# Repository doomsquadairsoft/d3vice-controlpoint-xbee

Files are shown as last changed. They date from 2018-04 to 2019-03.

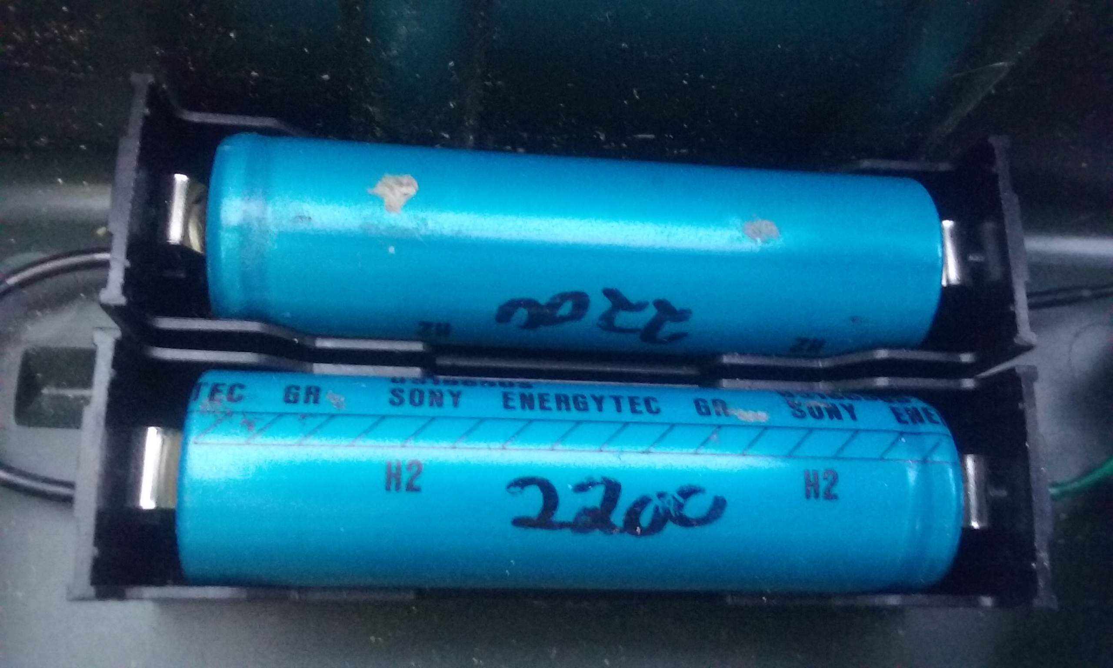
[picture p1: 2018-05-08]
other/pics/batteries.jpg

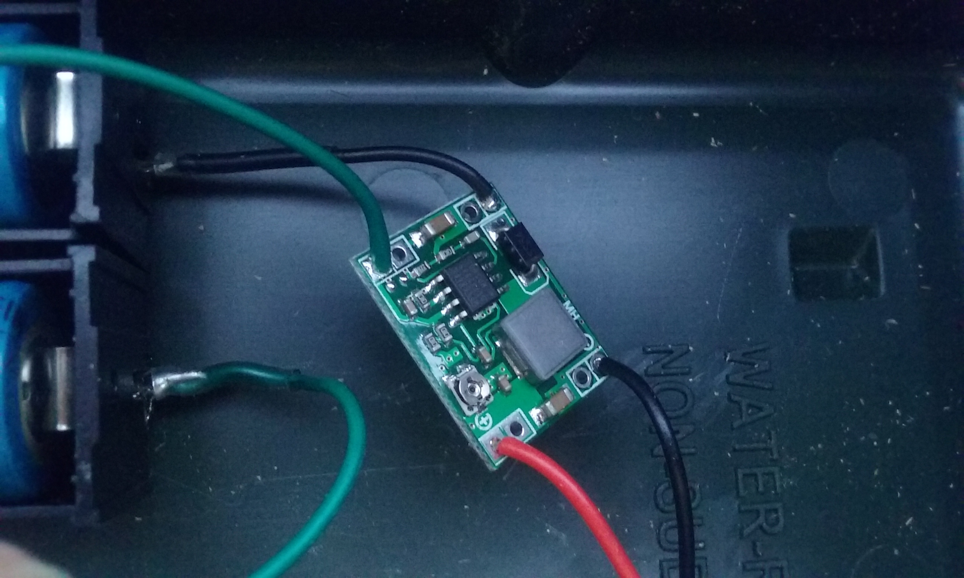
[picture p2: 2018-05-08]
other/pics/regulator.jpg

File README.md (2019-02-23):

# d3vice-controlpoint-xbee
Arduino Fio / XBee based D3VICE control point for Airsoft games

## Feedback

If you have used and enjoy this code base, I'd love to hear from you!



## Development setup process

  * Download, Install [Atom editor](https://atom.io)
  * Download, Install [Platformio](https://platformio.org/install/ide?install=atom) Atom package
  * Restart atom. Open Atom & PlatformIO then import this repo.

??? @TODO once I figure out the process after this
  * Install contributed libraries `Sketch > Include Libraries > Manage Libraries`
    * Adafruit NeoPixel library
    * XBee-Arduino library
  * Add your user account to tty and dialout groups (May or may not be required for your OS)
    * `sudo usermod -aG tty,dialout <YOUR_USERNAME_HERE>`

## Enclosure Ideas

  * [MTM Survivor Dry Box with O-Ring Seal, Large](https://www.amazon.com/MTM-Survivor-Ring-Orange-Large/dp/B002KENWZY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)
  * [Seahorse SE-300 Protective Case Without Foam](https://www.amazon.com/Seahorse-Protective-Case-without-Orange/dp/B001A1TR1Q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)

## XBee

### Setup

To connect to the XBee, a [SparkFun FTDI Basic Breakout 3.3v](https://www.sparkfun.com/products/9873) is used along with an [Adafruit XBee Adapter kit v1.1](https://www.adafruit.com/product/126). As my Adafruit XBee adapter kit v1.1 is discontinued, the replacment seems to be Adafruit's [USB XBee Adapter](https://www.adafruit.com/product/247) which I haven't tested but should do the trick. A separate FTDI chip isn't necessary with that new model.

XCTU is the program for configuring XBee modules. It is cross-platform.

57600 baudrate

Set the controlpoint as an ZB Router API NOT a ZB Endpoint API! Endpoint will work, but has complications with sleep mode.

#### XCTU Troubleshootinghttps://www.youtube.com/watch?v=ChCHfJoo9CQ

Make sure if using it on linux, you add yourself to the `dialout` group. Example: `sudo usermod -a -G dialout chris`

Make sure Arduino IDE is closed when working with XCTU. Radio discovery can be finnicky, but it works when it works.

XCTU's download links on Digi's website are usually broken. Find the filename from the [download page](https://www.digi.com/products/xbee-rf-solutions/xctu-software/xctu#productsupport-drivers), then manually browse their [ftp server](ftp://ftp1.digi.com/support/utilities/) for the correct version of XCTU.

If you can't get XCTU to communicate with your XBee, the rule of thumb is keep trying. It doesn't always work the first or second time. Try the different connection methods as well, from discovery to manually entering XBee serial/USB configuration.

### Power

The XBee is very sensitive when it comes to power. It needs as close to 3.3V as possible. When using USB, the Fio gives it a clean 3.285V. 3.296 was acheived using the buck converter regulator and that seemed to do the trick. If you are attempting to remotely program the XBee using X-CTU, and the read process seems slow, it may be that the XBee is crashing when it tries to pull power. Check voltages and try again.

### IDs

#### PAN ID

0x73706F6B616E6561 (ASCII spokanea)

#### switzerland-robust

SH 0013A200
SL 40B51A26

#### borders-portals

SH 0013A200
SL 40B774EC

## Special Thanks

The following people have helped this project in some way, and deserve a mention. Thank you all for helping this project become a reality!

  * [BulldogLowell](https://forum.arduino.cc/index.php?action=profile;u=258955) for helping me with code when I got stuck
  * [gfvalvo](https://forum.arduino.cc/index.php?action=profile;u=557197) for helping me with code when I got stuck
  * [Jiggy-Ninja](https://forum.arduino.cc/index.php?action=profile;u=53253) a.k.a. [MarkRD](https://hackaday.io/MarkRD) for helping me with code when I got stuck

## Todo list

  * [x] Fix phase 3 issue where ttw is ???
  * [ ] Implement XBee
  * [ ] Implement debugging via XBee wireless link
  * [x] Fix button debounce issue
  * [x] Fix endless beep on phase >=1
  * [x] Add button hold logic
  * [x] Implement ButtonManager
  * [ ] Try LoRa radio [Moteino](https://lowpowerlab.com/shop/product/119) looks nice.

## Parts list

  * (2) 220 Ohm resistor (JP3 button LEDs) DEPRECATED -- The buttons have their own capacitor
  * (3) 10K Ohm resistor (x2 JP4 button switches, x1 Battery Voltage Divider)
  * (1) 100K Ohm resistor (Battery voltage divider)
  * (1) 470 Ohm resistor (R1 Level shifter)
  * (1) 100 Ohm resistor (R2 buzzer)
  * (1) [Arduino Fio](https://amzn.to/2vkoAoj)
  * (1) 900MHz series XBee S2B
  * (1) [Digi JF1R6-CR3-4I U.FL fem to RPSMA fem cable](https://www.mouser.com/productdetail/digi-international/jf1r6-cr3-4i?qs=YPg7lQ8MWSd%252bJ21AYb5tjA%3D%3D)
  * (1) [2.4GHz dipole antenna](https://www.mouser.com/ProductDetail/Laird-LS-Research/001-0001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) (@TODO this doesn't seem right)
  * (1) 5V Buzzer
  * (1) 1000 uF electrolytic capacitor
  * (1) [TI 74AHCT125](http://adafru.it/1787) (NeoPixel 3V to 5V level shifter)
  * (1) [Red Arcade pushbutton](https://amzn.to/2qzc0vI)
  * (1) [Blue Arcade pushbutton](https://amzn.to/2vszEjp)
  * (2) [18650 Cell holder](https://amzn.to/2JN0Lsh)
  * (2) 18650 Li-Ion 3.7V battery
  * (1) [Qunqi MP1584EN DC-DC Buck Converter](https://amzn.to/2EPh9oB)
    * (1) [Alternative Power supply 001](https://www.ebay.com/itm/Durable-Quality-DC-DC-12V-To-3-3V-5V-Buck-Step-down-Power-Supply-Module-RH/113014911452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)
  * (1) [MTM Survivor Dry Box with O-Ring](https://amzn.to/2JQuaSx)
  * (1) [Medium keyswitch](https://www.sparkfun.com/products/retired/11473)
  * (n) [24 AWG copper wire](https://amzn.to/2FrzB6S)
  * (2) [Chasis handles](https://www.mouser.com/ProductDetail/RAF-Electronic-Hardware/8075-440-A-24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)
  * (?) [4-40 bolts](https://www.banggood.com/4-40-UNC-Stainless-Steel-Hex-Socket-Head-Cap-Screws-Nuts-Assortment-Kit-126pcs-p-1147256.html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)
  * (?) [LED Strip Housing](https://www.ebay.com/itm/50cm-U-V-YW-Aluminium-Housing-Holder-For-LED-Strip-Light-Bar-Under-Cabinet-Lamp/372358319157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)
  * (2) [Arcade Button Quick-Connect Wire Pairs - 0.11"](https://www.adafruit.com/product/1152)

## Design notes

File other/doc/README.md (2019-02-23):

# d3vice-controlpoint-xbee Documentation

Here is documentation for this project.

Phases.md a description of phase numbers
bom.csv a Bill of Materials for ordering PCB assembly

## PCB notes

Want list for future revisions

  * More clearance for XBee so it doesn't touch the side of the enclosure
  * Extra space around headers so JST header sockets will fit
  * Remove Button LED resistors
  * Add battery monitor circuit
  * Label all resistor values
  * LoRa radio footprint. NO shitty U.FL connectors!
  * ATMega328p chip instead of arduino
  * Caps & other stuff for ^
  * Power supply circuitry
  * SMT instead of TH

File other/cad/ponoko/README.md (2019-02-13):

# Ponoko designs

Here are the desgigns for laser cut panels and mounts. Buttons, LEDs, and electronics mount to this panel for a clean look and function. Panels are designed to fit inside [MTM Survivor Dry Box (large)](https://amzn.to/2jgJ5JL).

## Design notes

### Mk1 (cut)

130mm x 213mm **PERFECT**
Rounded corners 15.5mm radius **TOO SMALL**
Large button holes 28mm diameter **PERFECT**
Small keyswitch hole 11.5mm diameter **PERFECT**
NeoPixel hole 9mm diameter **TOO SMALL** (please make it 12.5mm)
50mm depth **TOO SHALLOW** (please make it 85mm)
Material thickness 0.157 inches 4mm

### Mk2 (cut)

130mm x 213mm
Rounded corners 25mm diameter
Large button holes 28mm diameter
Small keyswitch hole 11.5mm diameter
NeoPixel hole 12.5mm
85mm depth
Material thickness 0.157 inches (4mm)
Add holes for button protector/panel handle. up to 25mm height, 70mm width.
handle holes 2.234mm **TOO SMALL**

### Mk3 (on order)

Enlarged handle holes to 2.434mm **COMPLETE**
Removed neopixel hole **COMPLETE**
Added SMA-RP hole and mounting platform **COMPLETE**
Add mounting holes for PCB (2.234mm diameter) **COMPLETE**
Added font labels 'Bitstream Vera Sans'. **COMPLETE**
Added DooM Squad logo & Model name 'DooM D3VICE 2B' **COMPLETE**
Added cutout for neopixel strip housing **COMPLETE**

### Mk4 (future)

Add mini (DooM Squad branded) airsoft targets using extra space P2 (example: https://www.thingiverse.com/thing:1920712)

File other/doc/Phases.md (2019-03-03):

## Phases

Number - Description - LED Color

Phase 0 - Test Phase - Red
Phase 1 - Hello Phase - Yellow chase
Phase 2 - Game mode select - Blue
Phase 3 - Domination select TTW - Poop Green
Phase 4 - Domination running - Various
Phase 5 - Domination paused - purple
Phase 6 - Domination win - cyan
Phase 7 - Button test phase - None
Phase 8 - Battery test phase - None
Phase 9 - RSSI test phase - None
Phase 10 - -
Phase 11 - -
Phase 12 - Diffusal sel duration - pink
Phase 13 - Diffusal running - turquoise
Phase 14 - Diffusal paused - gold
Phase 15 - -
Phase 16 - -
Phase 17 - -
Phase 18 - Sector Control select ??? -
Phase 19 - Sector Control running -
Phase 20 - Sector Control paused -
Phase 21 - Sector Control win -
Phase 22 -
Phase 23 -
Phase 24 -
Phase 25 - SectorControl alternate mode

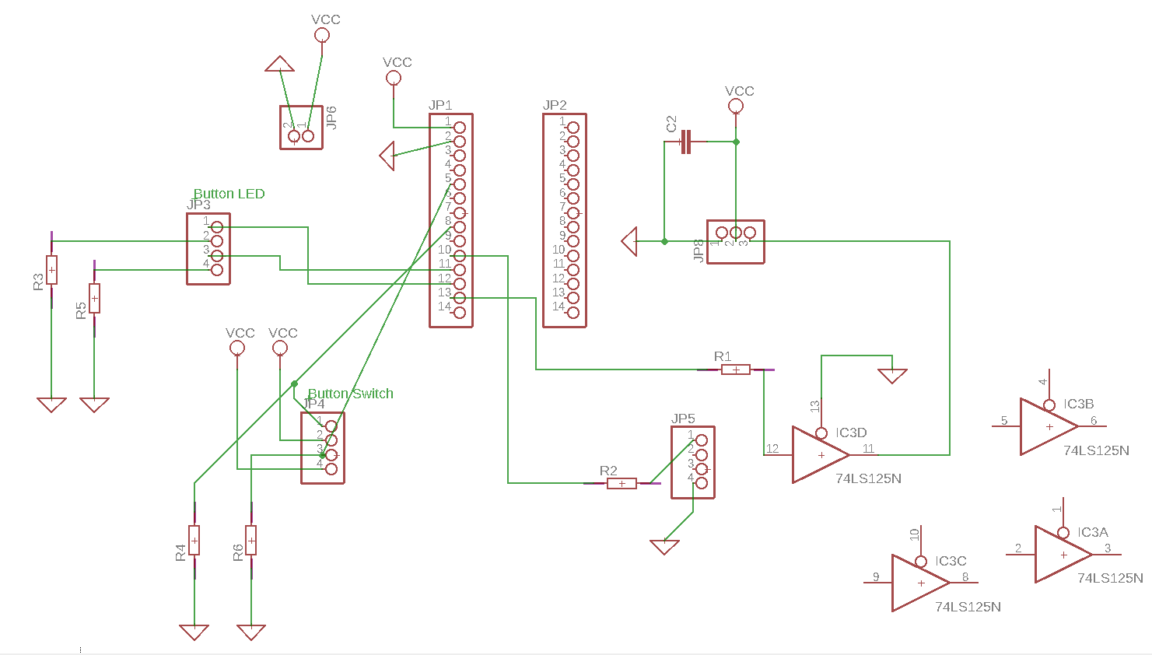
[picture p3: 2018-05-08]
other/pics/pcbschematic.png

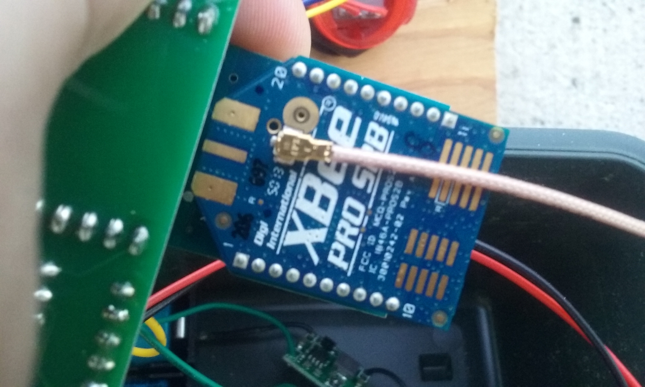
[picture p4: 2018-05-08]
other/pics/xbee.jpg

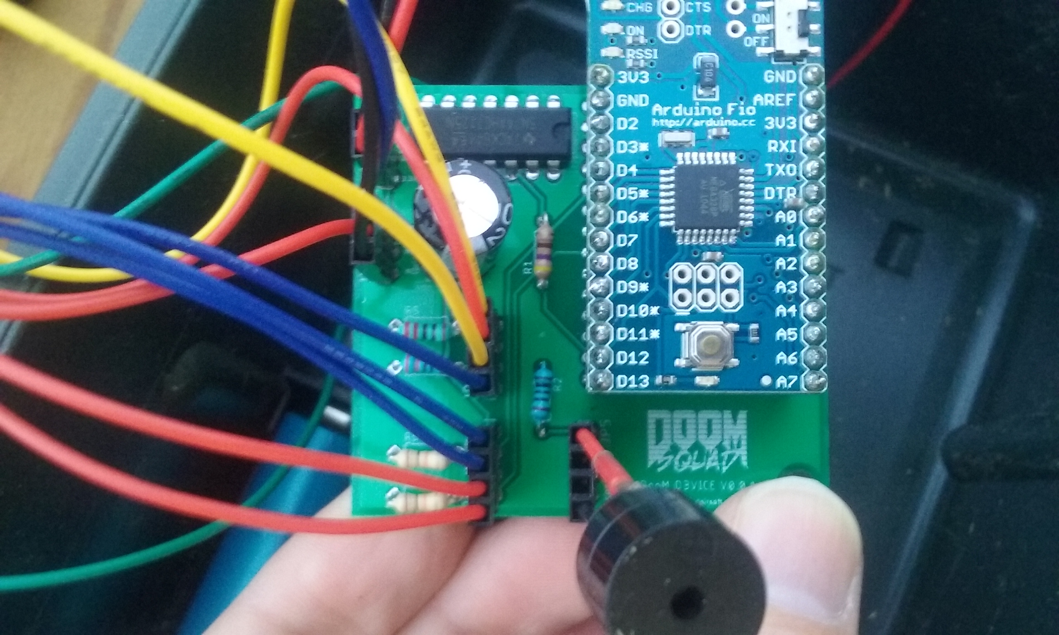
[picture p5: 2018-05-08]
other/pics/pcbview.jpg

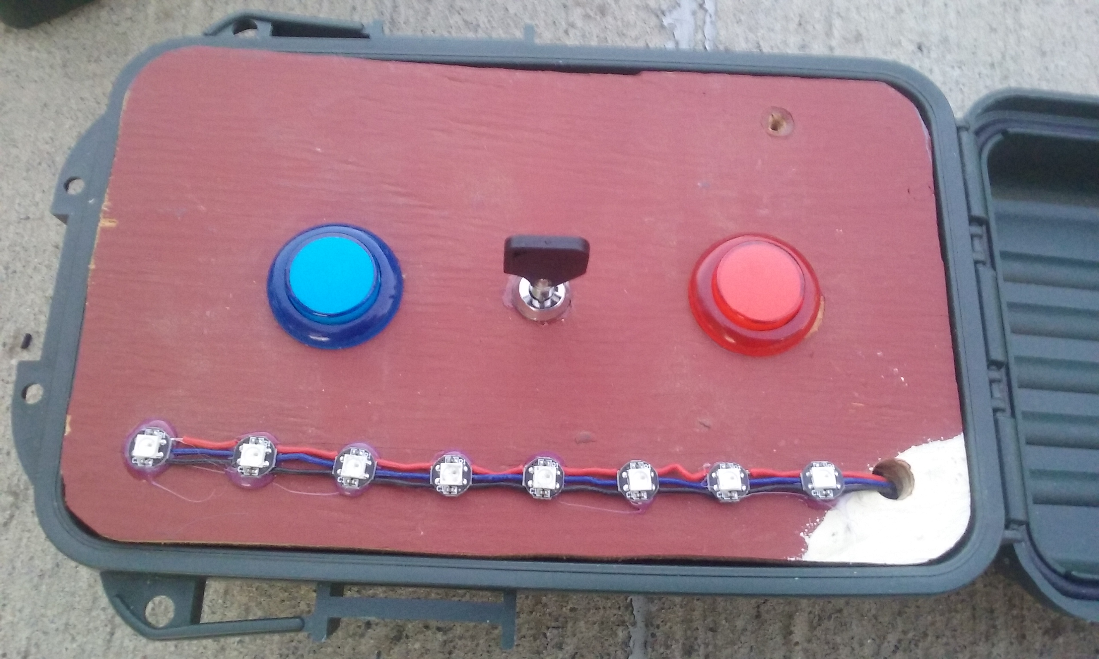
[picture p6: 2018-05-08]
other/pics/controlpoint.jpg

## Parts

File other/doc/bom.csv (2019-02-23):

Designator | MPN/Seeed SKU | Qty | Link
C1,C2,C3,C4,C5 | RHA0J471MCN1GS | 5 | https://www.digikey.com.cn/product-detail/zh/nichicon/RHA0J471MCN1GS/493-3771-1-ND/2209480
A1,A4 | RH0111-30002 | 2 | https://statics3.seeedstudio.com/images/opl/datasheet/318020010.pdf
D1 | CYBLE-014008-00 | 1 | https://www.digikey.com.cn/product-detail/zh/cypress-semiconductor-corp/CYBLE-014008-00/428-3600-1-ND/6052585

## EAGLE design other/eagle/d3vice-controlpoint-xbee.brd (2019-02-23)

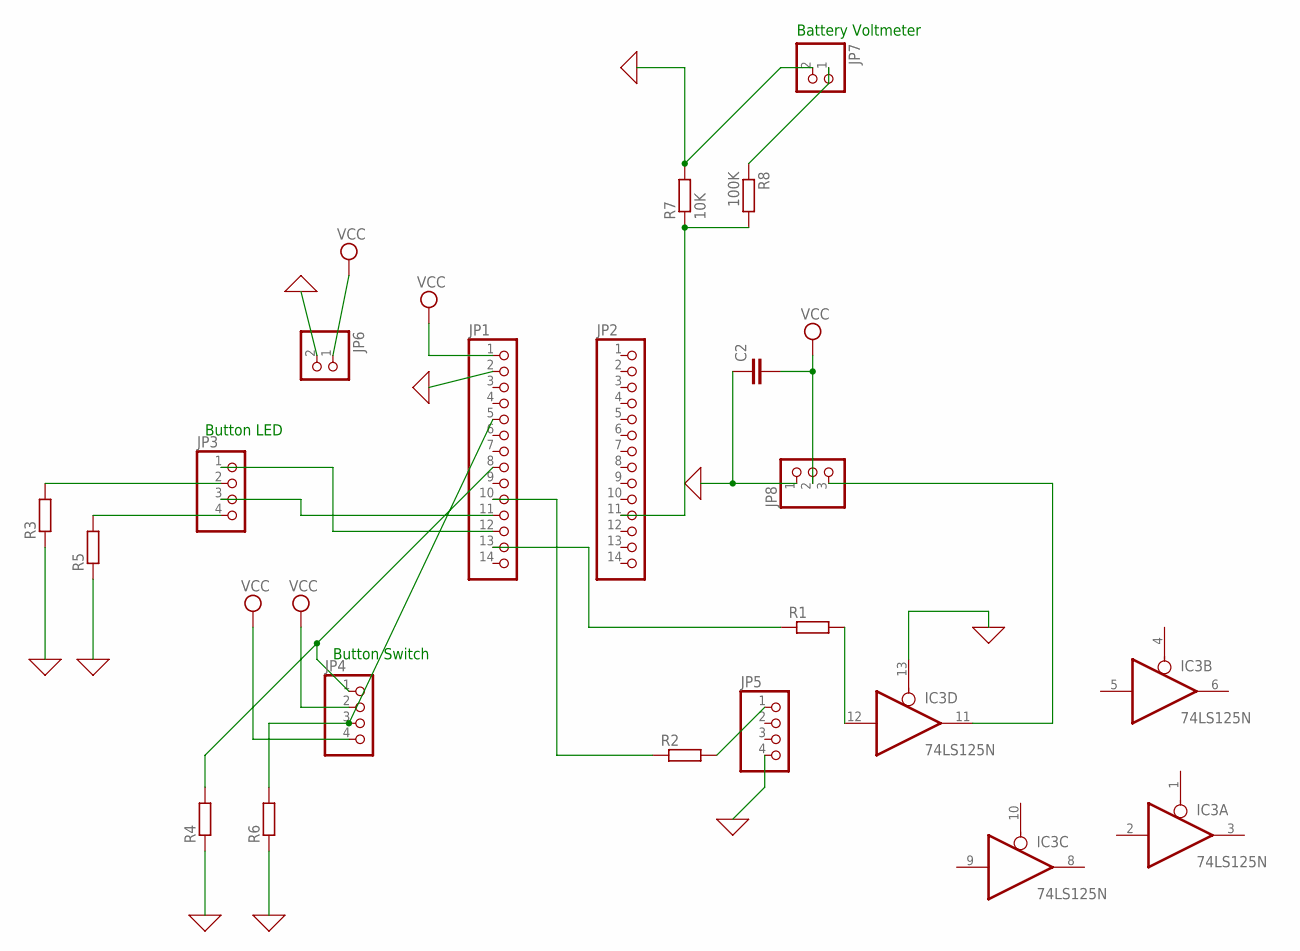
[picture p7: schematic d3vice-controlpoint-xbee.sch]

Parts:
C2: C-EU050-045X075; C050-045X075
IC3: 74LS125N; DIL14
JP1, JP2: PINHD-1X14; 1X14
JP3, JP4, JP5: PINHD-1X4; 1X04
JP6, JP7: PINHD-1X2; 1X02
JP8: PINHD-1X3; 1X03
R1, R2, R3, R4, R5, R6: R0204/7; 0204/7
R7: 10K; 0204/7
R8: 100K; 0204/7

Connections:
0: JP7.2, R7.2
GND: C2.1, IC3.7 (GND), IC3.13 (OE), JP1.2, JP5.4, JP6.2, JP8.1, R3.1, R4.1, R5.1, R6.1
unnamed: JP2.11, R7.1, R8.2
unnamed: IC3.11 (O), JP8.3
unnamed: IC3.12 (I), R1.2
unnamed: JP5.1, R2.2
unnamed: JP1.5, JP4.3, R6.2
unnamed: JP1.13, R1.1
unnamed: JP1.10, R2.1
unnamed: JP1.11, JP3.3
unnamed: JP3.4, R5.2
unnamed: JP3.2, R3.2
unnamed: JP1.12, JP3.1
unnamed: JP7.1, R8.1
unnamed: JP1.8, JP4.1, R4.2
VCC: C2.2, IC3.14 (VCC), JP1.1, JP4.2, JP4.4, JP6.1, JP8.2

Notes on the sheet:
Button LED
Button Switch
Battery Voltmeter

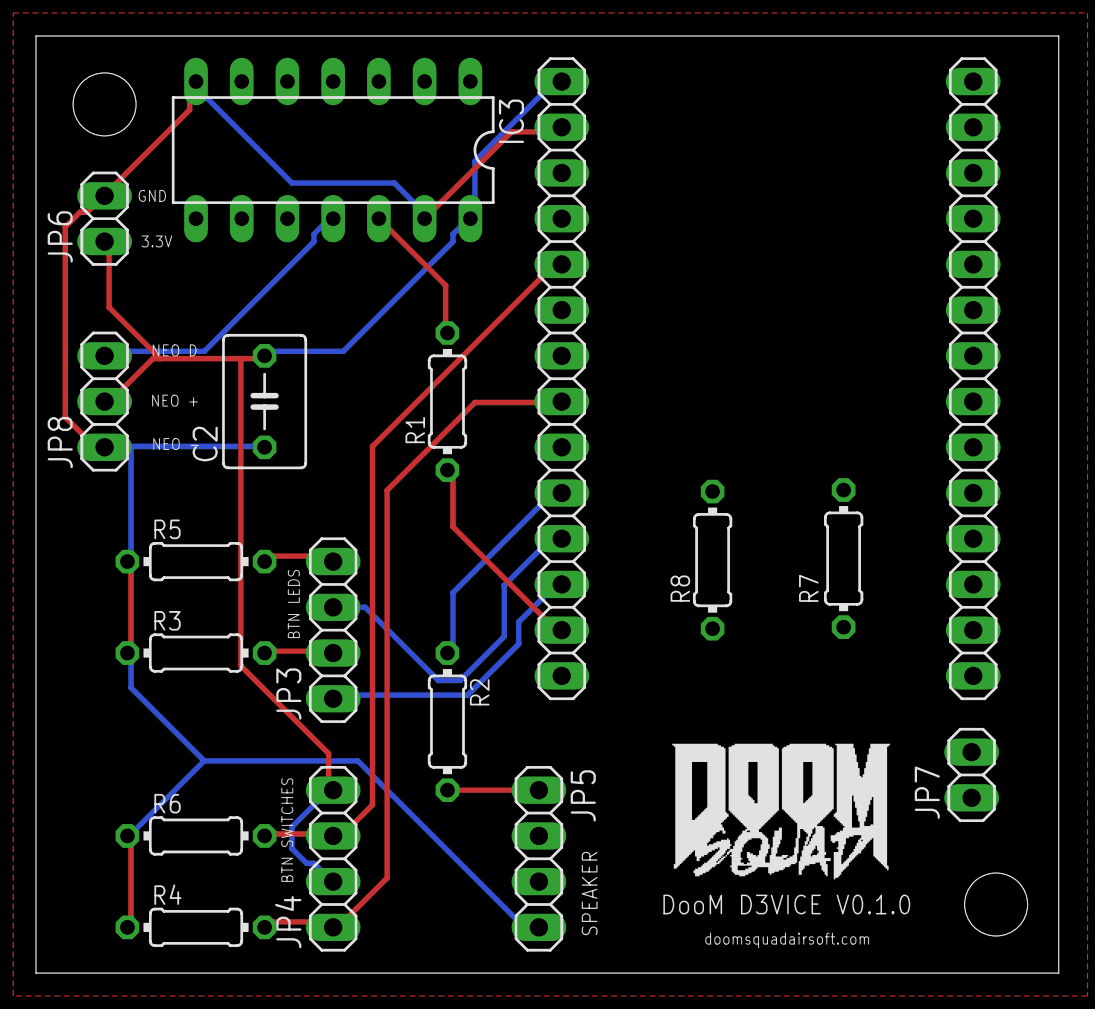
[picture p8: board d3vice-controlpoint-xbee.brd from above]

Board: 2 copper layers, 56.8 x 52.1 mm, 18 parts (0 on the bottom side), 16 nets.

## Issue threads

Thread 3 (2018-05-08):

XBee producing unsafe amount of heat

insanity54, 2018-05-08:
The XBee is getting so hot that the Arduino sketch crashes and restarts.

I'm thinking this is a PCB issue, but it also could have been a problem from before, not sure.

https://youtu.be/A0jY4YS_W3g

insanity54, 2018-07-25:
We have determined that this is a damaged XBee. Power supply voltage spike is suspect. #7 would fix.

insanity54, 2018-07-29:
Problem discovered is that https://github.com/doomsquadairsoft/d3vice-controlpoint-xbee/blob/920612e500f99a175a119ef6e3825442c42cf81c/d3vice-controlpoint-xbee/d3vice-controlpoint-xbee.ino transmits constantly during phase 1. Not good!  I'm guessing there was a problem with one of the XBees (maybe the shitty U.FL antenna lead?) paired with continuous transmission, overheat! Adding a delay will fix.

insanity54, 2018-11-04:
Closing for now, as faulty hardware is the suspect.

Closed 2018-11-04.

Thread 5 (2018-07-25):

U.FL connectors disconnect often

insanity54, 2018-07-25:
Please phase out U.FL connectors because they have a tendency to become disconnected!

insanity54, 2018-08-01:
We will use silicone glue for the U.FL XBees we have left

Closed 2018-08-01.

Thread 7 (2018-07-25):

Power supply should not be adjustable

insanity54, 2018-07-25:
The power supply should not have an adjustment screw. Moving parts are prone to failure from vibration, bumps, etc.

insanity54, 2018-11-04:
I think the adjustment screw is an catastrophic failure waiting to happen. Murphy's law should be respected-- if it can go wrong, it will go wrong! Switch to a different power supply! Affects #8

insanity54, 2019-02-23:
Swapped it out with a non-adjustable type

Closed 2019-02-23.

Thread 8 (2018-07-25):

Power supply is not secure

insanity54, 2018-07-25:
The power supply flops around given slack in the power wiring. The main board does not stay put with Velcro. A better solution for mounting the modules to the inside of the box is preferred.

insanity54, 2018-11-04:
I'm thinking of copious amounts of hot glue to secure the power supply to the 18650 holder. (depends on outcome of #11)

insanity54, 2019-02-23:
Fixed with velcro

Closed 2019-02-23.

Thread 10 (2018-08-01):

Heat concerns

insanity54, 2018-08-01:
they get hot. A larger battery #11 would allow a fan

insanity54, 2019-03-05:
I'm going to close this because I think this problem was related to #3 which was due to faulty hardware

Closed 2019-03-05.

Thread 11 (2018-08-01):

Battery Capacity concerns

insanity54, 2018-08-01:
Will the 2 18650 batteries drive the unit all day long?

insanity54, 2018-08-01:
Airsoft batteries will be best to switch to

insanity54, 2019-02-23:
Data is required to determine if action is needed. We need to find an average runtime on a full charge.

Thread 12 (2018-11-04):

Acrylic Skeleton Antenna mount

insanity54, 2018-11-04:
The antenna mount is undecided. The U.FL connector flops around in the case

insanity54, 2018-11-04:
laser cut panel Mk5 should solve. pending production.

insanity54, 2019-02-23:
Antenna mount is added.

Closed 2019-02-23.

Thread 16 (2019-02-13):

Add battery monitor arduino code

insanity54, 2019-02-13:
No wiring required! Just some code.

https://provideyourown.com/2012/secret-arduino-voltmeter-measure-battery-voltage/

insanity54, 2019-02-23:
Added in f58b4b407942eb7ca7dcf533041bb838ddc40454

Closed 2019-02-23.

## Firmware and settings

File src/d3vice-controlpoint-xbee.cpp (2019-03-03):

/**
 * d3vice-controlpoint-xbee
 *
 * DESCRIPTION
 *   Arduino Fio / XBee based D3VICE control point for Airsoft games.
 *   Makes king of the hill or Battlefield style sector control games easy.
 *
 *
 * PINOUTS
 *
 *   D4  Button 1
 *   D7  Button 2
 *   D9  Piezo Speaker
 *   D10 Button 1 LED
 *   D11 Button 2 LED
 *   D12 Neopixel
 *   D13 Onboard LED
 *   A4  Battery voltage sense
 *
 *
 * LICENSE
 *   The Unlicense <https://unlicense.org>
 *
 *
 * AUTHOR
 *   Chris Grimmett <chris@grimtech.net>
 *
 *
 * CODE REPOSITORY
 *   https://github.com/doomsquadairsoft/d3vice-controlpoint-xbee
 *
 *
 */


/**
 * Contributed libraries
 */
#include <Adafruit_NeoPixel.h>
#include <XBee.h>
#include <JC_Button.h> // https://github.com/JChristensen/JC_Button


/**
 * DooM Squad Libraries
 */
//#include "Button.h"



// pin definitions
#define button0Pin 7
#define button1Pin 4
#define button0LEDPin 10
#define button1LEDPin 11
#define onboardLEDPin 13
#define neopixelPin 12
#define buzzerPin 9
#define sleepPin 6
#define batteryPin A4


/**
 * Constants
 */
const bool RED = 0;
const bool BLU = 1;
const int GRY = 2;
const int BTN_RELEASED = 0;
const int BTN_PRESSED = 1;
const int BTN_HELD = 2;
const int BTN_LOCKED = 3;



/**
 * XBee configuration
 *
 * Here are the addresses the controlpoint may need
 */
uint32_t xbeeBroadcastSH = 0x00000000;
uint32_t xbeeBroadcastSL = 0x0000FFFF;
uint32_t xbeeGatewaySH = 0x0013A200;
uint32_t xbeeGatewaySL = 0x40B774EC;

/**
 * xbee status led config (temporary @todo deleteme)
 */
int statusLed = button0LEDPin;
int errorLed = button1LEDPin;


/**
 * LED state
 */
uint8_t breathState = 0;
float sinIn = 4.712;
bool isInhale = 0;
bool isLit = 0;
uint16_t scannerPosition = 0;


/**
 * Phase
 */
int phase = 0; // startup (initial) phase
int lastPhase = 1;


/**
 * Timers
 */
unsigned long lastBroadcastHoldEvent = 0;
unsigned long lastStandbyTime = 0;
unsigned long lastAnimationTime = 0;
unsigned long lastXEvent = 0;
unsigned long timeToCapture = 5000; // the time it takes to capture a point.
unsigned long lastPhase19Check = 250;
unsigned long lastPhase25Check = 250;
unsigned long lastCaptureTime = 0;



/**
 * Sector Control State
 */
uint8_t lastControllingTeam = GRY;
uint8_t lastCappingTeam = GRY;
uint8_t redProgress = 0;
uint8_t bluProgress = 0;


/**
 * Battery voltage read state
 */
int analogInput = 0;
float vout = 0.0;
float vin = 0.0;
float R1 = 100000.00; // resistance of R1 (100K) -see text!
float R2 = 10000.00; // resistance of R2 (10K) - see text!
int value = 0;



/**
 * instantiate class objects
 */
XBee xbee = XBee();
uint8_t payloadLength = 10;
uint8_t payload[] = { 48 };
unsigned long lastGreetTime = 0;
XBeeAddress64 gatewayAddress = XBeeAddress64(xbeeGatewaySH, xbeeGatewaySL);
ZBTxRequest zbRequest = ZBTxRequest(gatewayAddress, payload, payloadLength); // address, payload, size
ZBTxStatusResponse zbResponse = ZBTxStatusResponse();
ZBRxResponse rx = ZBRxResponse();
Button team0Button = Button(button0Pin, 25, true, false);
Button team1Button = Button(button1Pin, 25, true, false);


// Parameter 1 = number of pixels in strip
// Parameter 2 = Arduino pin number (most are valid)
// Parameter 3 = pixel type flags, add together as needed:
//   NEO_KHZ800  800 KHz bitstream (most NeoPixel products w/WS2812 LEDs)
//   NEO_KHZ400  400 KHz (classic 'v1' (not v2) FLORA pixels, WS2811 drivers)
//   NEO_GRB     Pixels are wired for GRB bitstream (most NeoPixel products)
//   NEO_RGB     Pixels are wired for RGB bitstream (v1 FLORA pixels, not v2)
//   NEO_RGBW    Pixels are wired for RGBW bitstream (NeoPixel RGBW products)
Adafruit_NeoPixel strip = Adafruit_NeoPixel(8, neopixelPin, NEO_GRB + NEO_KHZ800);



/**
 * configuration of the team's color (for neopixels)
 */
uint32_t redColorBlinding = strip.Color(255, 0, 0);
uint32_t bluColorBlinding = strip.Color(0, 0, 255);
uint32_t gryColorBlinding = strip.Color(50, 50, 50);

uint32_t redColorDim = strip.Color(85, 0, 0);
uint32_t bluColorDim = strip.Color(0, 0, 85);
uint32_t gryColorDim = strip.Color(17, 17, 17);
uint32_t ylwColorDim = strip.Color(20, 20, 0);
uint32_t blkColorOff = strip.Color(0, 0, 0);



void setup() {
        pinMode(onboardLEDPin, OUTPUT);
        pinMode(button0LEDPin, OUTPUT);
        pinMode(button1LEDPin, OUTPUT);
        pinMode(buzzerPin, OUTPUT);
        pinMode(neopixelPin, OUTPUT);
        pinMode(button0Pin, INPUT);
        pinMode(button1Pin, INPUT);
        pinMode(batteryPin, INPUT);
        pinMode(sleepPin, OUTPUT);
        digitalWrite(sleepPin, LOW);

        team0Button.begin();
        team1Button.begin();

        Serial.begin(57600);
        xbee.setSerial(Serial);

        strip.begin();
        strip.show(); // Initialize all pixels to 'off'

        /**
         * Init ADC
         */
  #if defined(__AVR_ATmega32U4__) || defined(__AVR_ATmega1280__) || defined(__AVR_ATmega2560__)
        ADMUX = _BV(REFS0) | _BV(MUX4) | _BV(MUX3) | _BV(MUX2) | _BV(MUX1);
  #elif defined (__AVR_ATtiny24__) || defined(__AVR_ATtiny44__) || defined(__AVR_ATtiny84__)
        ADMUX = _BV(MUX5) | _BV(MUX0);
  #elif defined (__AVR_ATtiny25__) || defined(__AVR_ATtiny45__) || defined(__AVR_ATtiny85__)
        ADMUX = _BV(MUX3) | _BV(MUX2);
  #else
        ADMUX = _BV(REFS0) | _BV(MUX3) | _BV(MUX2) | _BV(MUX1);
  #endif
}






void setProgressBar(bool teamNumber, uint16_t percentage) {
        // determine how many pixels to turn on
        uint16_t split = (100 / strip.numPixels());
        uint16_t numberOfNeopixelsToLight = (percentage / split);

        // clear all neopixels
        for(uint16_t i=0; i<strip.numPixels(); i++) {
                strip.setPixelColor(i, strip.Color(0, 0, 0));
        }

        // light up the necessary neopixels
        if (!teamNumber) {
                // red goes right to left
                for(uint16_t i=0; i<numberOfNeopixelsToLight-1; i++) {
                        strip.setPixelColor(i, strip.Color(20, 0, 0));
                }
        } else {
                // blu goes left to right
                // teh bug is here vvvv
                uint16_t endPixel = strip.numPixels()-numberOfNeopixelsToLight;
                for(uint16_t i=strip.numPixels(); i>endPixel; i--) {
                        strip.setPixelColor(i, strip.Color(0, 0, 20));
                }
        }
        strip.show();
}


void flashLed(int pin, int times, int wait) {

        for (int i = 0; i < times; i++) {
                digitalWrite(pin, HIGH);
                delay(wait);
                digitalWrite(pin, LOW);

                if (i + 1 < times) {
                        delay(wait);
                }
        }
}



/**
 * readInternalVcc
 * Read the CHIP voltage. (not the battery voltage)
 * Read the 1.1V reference against AVcc
 * greetz https://provideyourown.com/2012/secret-arduino-voltmeter-measure-battery-voltage/ (voltage calculation code)
 * gratz http://maxembedded.com/2011/06/the-adc-of-the-avr/ (ADCSRA register explanation)
 */
long readInternalVcc() {
        #if defined(__AVR_ATmega32U4__) || defined(__AVR_ATmega1280__) || defined(__AVR_ATmega2560__)
        ADMUX = _BV(REFS0) | _BV(MUX4) | _BV(MUX3) | _BV(MUX2) | _BV(MUX1);
        #elif defined (__AVR_ATtiny24__) || defined(__AVR_ATtiny44__) || defined(__AVR_ATtiny84__)
        ADMUX = _BV(MUX5) | _BV(MUX0);
        #elif defined (__AVR_ATtiny25__) || defined(__AVR_ATtiny45__) || defined(__AVR_ATtiny85__)
        ADMUX = _BV(MUX3) | _BV(MUX2);
        #else
        ADMUX = _BV(REFS0) | _BV(MUX3) | _BV(MUX2) | _BV(MUX1);
        #endif

        delay(2);
        ADCSRA |= _BV(ADSC); // Start conversion
        while (bit_is_set(ADCSRA,ADSC)); // loop, doing nothing until the measuring is complete
        uint8_t low = ADCL; // result of measurement is stored in ADCL (low) and ADCH (high)
        uint8_t high = ADCH;
        long result = (high<<8) | low;
        // Calculate Vcc (in mV); 1125300 = 1.1*1023*1000
        // this is subject to PER D3VICE calibration, as internal 1.1V reference on ATmega vary from 1.0 to 1.2 volts.
        // to calibrate, adjust 1125300L constant using the following formula--
        // scale_constant = internal1.1Ref * 1023 * 1000
        // To get internal1.1Ref, gather Vcc1 and Vcc2.
        // To get Vcc1, use a voltmeter to measure Arduino's Vcc.
        // To get Vcc2, run this function, readInternalVcc().
        // Then, internal1.1Ref can be calculated using the following formula--
        // internal1.1Ref = 1.1 * Vcc1 (per voltmeter) / Vcc2 (per readVcc() function)
        result = 1125300L / result;
        return result;
}

/**
 * Read voltage on Pin A3
 * Compare against 1.1V internal reference for accuracy
 */
float readExternalVcc() {
        value = analogRead(batteryPin);

        // these next lines are good for converting to a float.
        // since we are sending over xbee, we prefer an int.
        // vout = (value * 3.3) / 1024.0;
        // vin = vout / (R2/(R1+R2));
        // return vin;
        return value;
}


void decrementBluProgress() {
        // points are accumulated at a rate of
        // 255 points per n milliseconds
        // where n is timeToCapture.
        //
        // Because phase19 runs 4 times a second,
        // The algo which determines the amount to decrement per second is
        // 255 / 5000 = 0.051 points per ms
        // 0.051 * 1000 = 51 points per second
        // 51 / 4 = 12.75 points per 1/4 second

        // 255/n*250 = amount to decrement per 1/4 second (where n is timeToCapture)


        float delta = 255.0 / timeToCapture * 250;
        long result = bluProgress - delta;
        if (result <= 0) {
                bluProgress = 0;
        }

        else {
                bluProgress -= delta;
        }

}




void decrementRedProgress() {
        float delta = 255.0 / timeToCapture * 250;
        long result = redProgress - delta;
        if (result <= 0) {
                redProgress = 0;
        }

        else {
                redProgress -= delta;
        }
}




void incrementBluProgress() {
        uint8_t delta = 255.0 / timeToCapture * 250;
        long result = bluProgress + delta;

        if (result >= 255) {
                bluProgress = 255;
                lastCaptureTime = millis();
                lastControllingTeam = BLU;
        }

        else {
                bluProgress += delta;
        }
}





void incrementRedProgress() {


        uint8_t delta = 255.0 / timeToCapture * 250;
        long result = redProgress + delta;

        if (result >= 255) {
                redProgress = 255;
                lastCaptureTime = millis();
                lastControllingTeam = RED;
        }

        else {
                redProgress += delta;
        }
}


/**
 * @TODO
 *
 * Log a button/capture event to PROGMEM.
 * Later on when XBee connection is established,
 * Sync events with controlpointer for later scoring.
 */
void logEvent() {

}



void broadcastHoldEvent(int team) {
        // rate limiting
        if (millis() - lastBroadcastHoldEvent > 1000) {

                /**
                 * Send a button hold event
                 */
                payload[0] = 'D';
                payload[1] = 'C';
                payload[2] = 'X';
                payload[3] = 'B';
                payload[4] = 'H';

                if (team == 0) {
                        payload[5] = '0';
                }
                else if (team == 1) {
                        payload[5] = '1';
                }


                xbee.send(zbRequest);


                lastBroadcastHoldEvent = millis();
        }



        // flash TX indicator

        // after sending a tx request, we expect a status response
        // wait up to half second for the status response
        if (xbee.readPacket(1000)) {
                // got a response!

                // should be a znet tx status
                if (xbee.getResponse().getApiId() == ZB_TX_STATUS_RESPONSE) {
                        xbee.getResponse().getZBTxStatusResponse(zbResponse);

                        // get the delivery status, the fifth byte
                        if (zbResponse.getDeliveryStatus() == SUCCESS) {
                                // success.  time to celebrate
                        } else {
                                // the remote XBee did not receive our packet. is it powered on?
                        }
                }
        } else if (xbee.getResponse().isError()) {
                //nss.print("Error reading packet.  Error code: ");
                //nss.println(xbee.getResponse().getErrorCode());
        } else {
                // local XBee did not provide a timely TX Status Response -- should not happen
                flashLed(buzzerPin, 2, 100);
        }
}

//
//void doParse(&rx) {
//  for (uint8_t i=0; i<rx.getDataLength; i++) {
//    rx.getData(i);
//  }
//}

void listenForState() {
        /**
         * Listen for state changes from controlpointer
         */
        xbee.readPacket();
        if (xbee.getResponse().isAvailable()) {
                // we got a response
                if (xbee.getResponse().getApiId() == ZB_RX_RESPONSE) {
                        xbee.getResponse().getZBRxResponse(rx);

                        if (rx.getOption() == ZB_PACKET_ACKNOWLEDGED) {
                        }

                        else {
                        }




                        /**
                         * interpret the state updates
                         *
                         * https://github.com/doomsquadairsoft/d3vice-controlpoint-xbee/issues/2
                         */
//      if (dcxParser.getDataType() == STATE_UPDATE) {
//        controllingTeam = dcxParser.getData(CONTROLLING_TEAM);
//        redProgress = dcxParser.getData(RED_PROGRESS);
//        bluProgress = dcxParser.getData(BLU_PROGRESS);
//      }



                        if (
                                rx.getData(0) == 'D' &&
                                rx.getData(1) == 'C' &&
                                rx.getData(2) == 'X' &&
                                rx.getData(3) == 'S' &&
                                rx.getData(4) == 'T'
                                )
                        {
                                // we're getting a state update (ST)

                                if (rx.getData(5) == 'C' &&
                                    rx.getData(6) == 'T'
                                    )
                                {
                                        // Controlling Team
                                        //if (rx.getData(7) < 5) {
                                        if (rx.getData(7) == '0') {
                                                //controllingTeam = 0;
                                        }
                                        else if (rx.getData(7) == '1') {
                                                //controllingTeam = 1;
                                        }
                                        else if (rx.getData(7) == '2') {
                                                //controllingTeam = 2;
                                        }

                                }

                                if (rx.getData(8) == 'R' &&
                                    rx.getData(9) == 'P'
                                    )
                                {
                                        //if (rx.getData(10) < 101) {
                                        redProgress = rx.getData(10);
                                        //}
                                }

                                if (rx.getData(11) == 'B' &&
                                    rx.getData(12) == 'P'
                                    )
                                {
                                        //if (rx.getData(13) < 101) {
                                        bluProgress = rx.getData(13);
                                        //}
                                }
                        }
                }
        }
}





/**
 * Pulsate
 *
 * Compute the brightness of the LED in a pulsating fashion.
 */
uint8_t pulsate(uint8_t breathState) {

        if (isInhale) {
                if (breathState < 63) {
                        breathState += 4;
                }
                else {
                        isInhale = 0;
                }
        }
        else {
                if (breathState > 0) {
                        breathState -= 4;
                }
                else {
                        isInhale = 1;
                }
        }
        return breathState;

}



/**
 * Display the state on the NeoPixels
 */
void displayState() {

        /**
         * If either redProgress or bluProgress has reached 255 in the past 5 seconds,
         * pulsate the respective color indicating team capture
         */
        if (lastCaptureTime != 0 && millis() - lastCaptureTime < 5000) {
                breathState = pulsate(breathState);
                for(uint16_t i=0; i<strip.numPixels(); i++) {

                        if (redProgress == 255) {
                                strip.setPixelColor(i, strip.Color(breathState, 0, 0));
                        }
                        else if (bluProgress == 255) {
                                strip.setPixelColor(i, strip.Color(0, 0, breathState));
                        }
                        strip.show();
                }
        }


        /**
         * No full capture has occured in the last 5 seconds.
         * If either team has full control (xProgress == 255), Show the color of the controlling team
         * Display grey if no team has any progress points
         */
        else if (
                (redProgress == 255 && bluProgress == 255) ||
                (redProgress == 0 && bluProgress == 0)
                ) {


                if (redProgress == 0 && bluProgress == 0) {
                        for(uint16_t i=0; i<strip.numPixels(); i++) {
                                strip.setPixelColor(i, gryColorDim);
                                strip.show();
                        }
                }

                else if (redProgress == 255) {
                        for(uint16_t i=0; i<strip.numPixels(); i++) {
                                strip.setPixelColor(i, redColorDim);
                                strip.show();
                        }
                }

                else if (bluProgress == 255) {
                        for(uint16_t i=0; i<strip.numPixels(); i++) {
                                strip.setPixelColor(i, bluColorDim);
                                strip.show();
                        }
                }
        }


        /**
         * No full capture has occured in the last 5 seconds.
         * If neither team has full control, show progress bars.
         */
        else {

                // @TODO Revise

                // show color coded progress bar on pixels 0-8
                // show color coded progress bar on pixels 16-9


                uint8_t mappedBluProgress = map(bluProgress, 0, 255, 0, strip.numPixels());
                uint8_t mappedRedProgress = map(redProgress, 0, 255, 0, strip.numPixels());



                // clear all pixels
                for(uint16_t i=0; i<strip.numPixels(); i++) {
                        strip.setPixelColor(i, gryColorDim);
                }


//    /**
//     * lastControllingTeam was RED which means this will be a red bar
//     */
//    if (lastControllingTeam == RED) {
//      for(uint16_t i=0; i<mappedRedProgress; i++) {
//        strip.setPixelColor(i, redColor);
//      }
//    }
//
//    else if (lastControllingTeam == BLU) {
//      for(uint16_t i=0; i<mappedBluProgress; i++) {
//        strip.setPixelColor(i, bluColor);
//      }
//    }


                //else {




                if (redProgress == 0) {
                        for (uint16_t i=0; i<mappedBluProgress; i++) {
                                strip.setPixelColor(i, bluColorDim);
                        }
                }

                else if (bluProgress == 0) {
                        for (uint16_t i=0; i<mappedRedProgress; i++) {
                                strip.setPixelColor(i, redColorDim);
                        }
                }
                //}

                strip.show();



        }
}




// Fill the dots one after the other with a color
void colorWipe(uint32_t c, uint8_t wait) {
        for(uint16_t i=0; i<strip.numPixels(); i++) {
                strip.setPixelColor(i, c);
                strip.show();
                delay(wait);
        }
}

void pixelsOff() {
        for(uint16_t i=0; i<strip.numPixels(); i++) {
                strip.setPixelColor(i, strip.Color(0, 0, 0));
                strip.show();
        }
}
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
void loop()
{
        // poll pushbuttons for activity
        team0Button.read();
        team1Button.read();


        if (phase == 0) {
                runPhase0();
        }

        /**
         * HELLO Phase
         */
        else if (phase == 1) {
                runPhase1();
        }

        /**
         * Standby Phase
         */
        else if (phase == 2) {
                runPhase2();
        }

        else if (phase == 3) {
                runPhase3();
        }

        else if (phase == 4) {
                runPhase4();
        }

        else if (phase == 7) {
                runPhase7();
        }

        else if (phase == 8) {
                runPhase8();
        }

        else if (phase == 19) {
                runPhase19();
        }

        else if (phase == 20) {
                runPhase20();
        }

        else if (phase == 25) {
                runPhase25();
        }

}

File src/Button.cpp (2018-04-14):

#if defined(ARDUINO) && ARDUINO >= 100
    #include "Arduino.h"
#else
    #include "WProgram.h"
#endif
#include "Button.h"


Button::Button(uint8_t teamNumber, uint8_t buttonPin)
{
  _teamNumber = teamNumber;
  _buttonPin = buttonPin;
  _wasPressed = 0;
  _wasHeld = 0;
  _lastPressTime = 0;
  _lastReleaseTime = 0;
  _isLocked = 0;
}

/**
 * Button.update()
 * 
 * Determine the button's state
 */
void Button::update() {

  // reset toggle variables which only last for 1 tick
  if (_wasPressReleasedLastTick) { _wasPressReleasedLastTick = 0; }
  if (_wasHoldReleasedLastTick) { _wasHoldReleasedLastTick = 0; }

  
  // if the button was pressed last tick, and it is also pressed this tick, do nothing.
  if (digitalRead(_buttonPin) && _wasPressed) {

    // if the button is pressed and has been for 1 second, mark as held
    if (millis() - _lastPressTime > 1000 && !_wasHeld) {
      processHold();
    }
    
    return;
  }
  
  // if the button was not pressed last tick, but is pressed this tick, process press.
  else if (digitalRead(_buttonPin) && !_wasPressed) {
    processPress();
  }

  // if the button is not pressed this tick, but was pressed last tick, process press release.
  else if (!digitalRead(_buttonPin) && _wasPressed) {
    processPressRelease();
  }

  // if the button is not pressed this tick, but was held last tick, process hold release.
  else if (!digitalRead(_buttonPin) && _wasHeld) {
    processHoldRelease();
  }

  


}


/**
 * Do the action that the button should perform based on the current phase->
 */
void Button::processPress() {
//  // debug. determine the phase that the button class thinks it is
//  for (int i=0; i<_phase->getCurrentPhase(); i++) {
//      digitalWrite(9, HIGH);
//      delay(10);
//      digitalWrite(9, LOW);
//      delay(50);
//  }




  // set the wasPressed boolean to TRUE which will be queried in later ticks to see if the button state was changed since last tick
  _wasPressed = 1;
  

  // set a start press time to later be used to determine if the button is being held (multi-button press&hold functionality)
  _lastPressTime = millis();

   
}






/**
 * Do the release action that the button should perform based on the current phase->
 */
void Button::processPressRelease() {

    
  _wasPressed = 0;
  _wasHeld = 0;
  _lastReleaseTime = millis();
  _isLocked = 0;
  _wasPressReleasedLastTick = 1;

//  if (_teamNumber == 0) {
//  
//    for(int i=0; i<1; i++) {
//      digitalWrite(9, HIGH);
//      delay(15);
//      digitalWrite(9, LOW);
//      delay(15);
//    }
//    delay(100);
//  }
//
//  else {
//        for(int i=0; i<1; i++) {
//      digitalWrite(9, HIGH);
//      delay(115);
//      digitalWrite(9, LOW);
//      delay(15);
//    }
//    delay(100);
//  }

  
}


void Button::processHoldRelease() {
  _wasPressed = 0;
  _wasHeld = 0;
  _lastReleaseTime = millis();
  _isLocked = 0;
  _wasHoldReleasedLastTick = 1;
}




/**
 * processHold
 * 
 * the action to do when the button is held
 * 
 * This function is for single-button holds only.
 * multi-button holds are handled in ButtonManager.
 */
void Button::processHold() {
  _wasHeld = 1;


}


/**
 * getState
 * 
 * 0 released
 * 1 pressed
 * 2 held
 * 3 locked
 */
int Button::getState() {

  if (_isLocked) {
    return 3;
  }
  
  // if the latest press was more recent than the latest release, the button is physically pressed
  else if (digitalRead(_buttonPin) == HIGH) {

    // if the button has been pressed for less than 1000 ms, consider it pressed
    if (millis() - _lastPressTime < 1000) {
      return 1;
    }

    // if the button has been pressed for greater than or equal to 1000 ms, consider it held
    else {
      return 2;
    }
  }

  // if the latest release was more recent than the latest press, the button is released.
  else {
    return 0;
  }
}


/**
 * Prevent Button from returning anything except state 3.
 * Avoids problem where a press and hold triggers two phase changes rapid-fire.
 * Call this after the desired action was performed.
 * No other action can occur until button state 0 (button not pressed) occurs.
 * 
 */
void Button::lock()
{
  _isLocked = 1;
}





bool Button::wasPressReleasedLastTick()
{
  return _wasPressReleasedLastTick;
}

bool Button::wasHoldReleasedLastTick()
{
  if (_wasHoldReleasedLastTick) {
    return 1;
  }
  else {
    return 0;
  }
}

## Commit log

2017-12-04 button LEDs implemented
2017-12-05 implement strobing effect after button presses
2018-01-26 add saythanks button
2018-01-26 debugging button debouncing
2018-01-27 fix button debounce issue
    [Button.cpp, d3vice-controlpoint-xbee.ino]
2018-01-28 fix endless buzzer bug
    [d3vice-controlpoint-xbee.ino]
2018-01-29 add scaffolding for ButtonManager & multi-button holds
2018-01-31 fixing ButtonManager reference issue
    [Button.cpp, d3vice-controlpoint-xbee.ino]
2018-02-11 debugging phase3 button presses and ttw
2018-02-12 im stuck. Button _teamNumber is misbehaving
    [Button.cpp, d3vice-controlpoint-xbee.ino]
2018-02-23 fix button bug where both buttons had same teamNumber
    [Button.cpp, d3vice-controlpoint-xbee.ino]
2018-03-04 switch to references
2018-03-11 Fix rapid-fire phase advancement bug
    [Button.cpp, d3vice-controlpoint-xbee.ino]
2018-03-11 add Phase2 selection, implement holdRelease bug
    [Button.cpp, d3vice-controlpoint-xbee.ino]
2018-04-20 add parts list
    [Arduino-Fio-v22.brd, Arduino-Fio-v22.sch, bom.csv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]
2018-05-04 add cad files
2018-05-08 trim heatissue clip
2018-05-08 rotate vid, add pcb pics
2018-11-04 add mounting holes
    [Arduino-Fio-v22.sch]
2019-02-13 convert to PlatformIO project
    [Arduino-Fio-v22.brd, Arduino-Fio-v22.sch, bom.csv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]
2019-02-23 added battery voltage circuit
    [d3vice-controlpoint-xbee.brd, d3vice-controlpoint-xbee.sch]
2019-02-23 add battery testing phase
2019-02-23 add fio schematic
2019-02-23 update docs
    [bom.csv]
2019-02-26 switch to JC_Button library
2019-02-27 fix phase switching bug
    [d3vice-controlpoint-xbee.cpp]
2019-03-03 fix progress bar... almost
    [d3vice-controlpoint-xbee.cpp]
